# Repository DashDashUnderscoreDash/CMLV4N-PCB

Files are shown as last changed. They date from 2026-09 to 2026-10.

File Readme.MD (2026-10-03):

# **CMLV4N**

CMLV4N is an STM32 12u V4N style PCB with leafspring tadpole mounting featuring forced Cherry ML support

The goal of this PCB is to have a 40% keyboard that uses Cherry ML switches harvested from a Cherry G84-4100.

### PLEASE ENSURE YOU VERIFY THE SPACEBAR IS LARGE ENOUGH!!!! There are multiple models you can use for donor boards and some have too small of spacebar.

Due to the uneven u sizing on Cherry ML the enter key does not fill that entire area. The stabilizer positions for the enter also do not work as they are for a larger sized keycap. This is a compromise that needed to be made to make the layout work and a combination of skill issue. The stabilizer position on the enter does not work as the footprint is the incorrect size. Apologies!

~~Available~~ Sold out at [Dashkeebs](https://dashkeebs.bigcartel.com/product/cmlv4n-pcb) as of 10/1/26

### In this repo you will find:
```
- Layout options
- Images of PCB
- VIAL firmware
- STEP model of PCB
- Edgecuts of PCB
- Complete KiCad project
- Case files (STEP format)
```

VIAL firmware commissioned by [Moinboards.](https://moinboards.de/) Thank you again so much!

### KLC layout
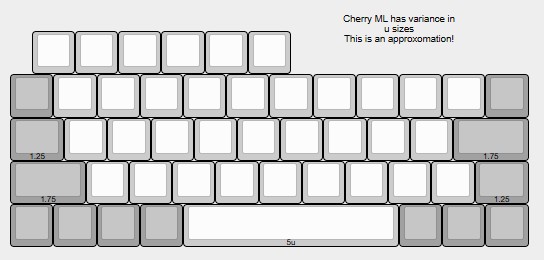
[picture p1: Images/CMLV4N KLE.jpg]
KLC layout


### PCB images
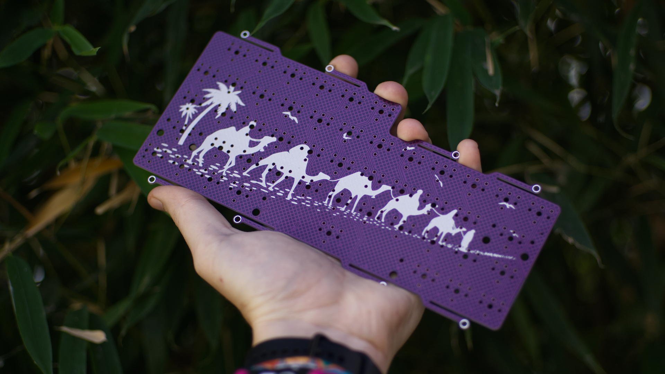
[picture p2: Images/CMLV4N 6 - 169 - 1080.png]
PCB Front

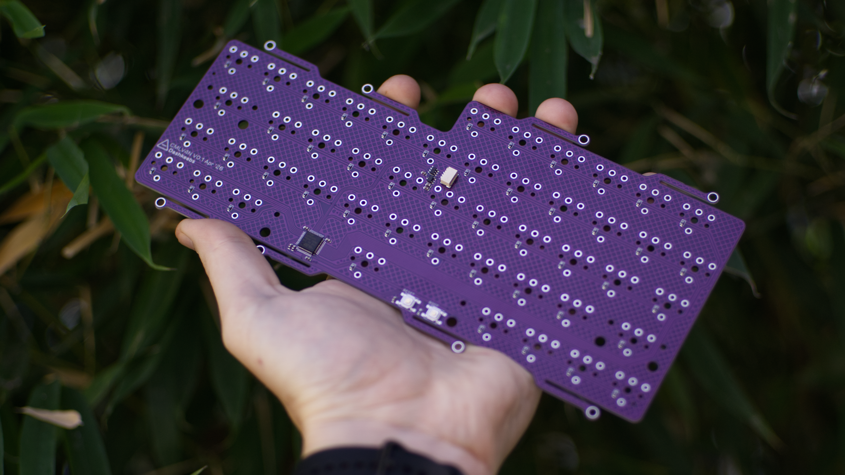
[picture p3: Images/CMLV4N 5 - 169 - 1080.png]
PCB Back


### Case image
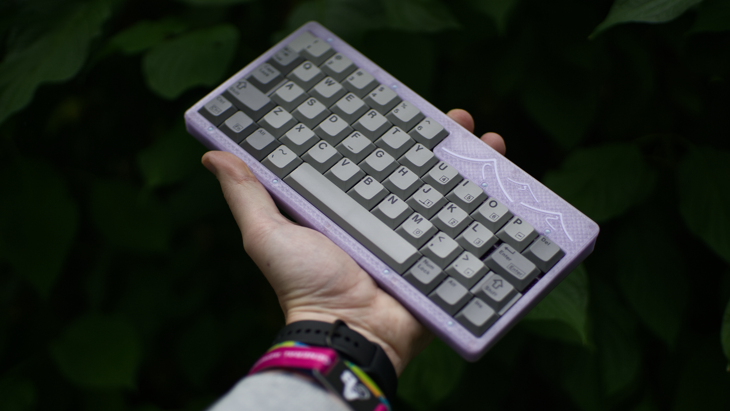
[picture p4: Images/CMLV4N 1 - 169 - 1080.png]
Case


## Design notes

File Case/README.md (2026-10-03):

# **CMLV4N 3d Printed Case**

__Items needed:__
- 1x [C3/C5 universal daughterboard](https://cannonkeys.com/products/unified-daughterboard-and-jst-cable)
- 1x [JST cable](https://www.aliexpress.us/item/3256809955750969.html) - Ideally very short. I used 6cm, 4 pin, "double reverse" cables. Longer cables can be used, but they may negativley impact the flex
- 4x [SKUF feet](https://keeb.io/products/skuf-silicone-rubber-keyboard-feet)
- 8x [Geon tadpoles](https://saberkeebs.com/products/geon-tadpoles) - The softer the better in my opinion
- 8x [M2 heatsets](https://a.co/d/0grCwzam) - *M2/H3/D3 in case link dies in the future*
- 8x [Wheel weights](https://a.co/d/0inzJoTX) - *0.65"/16.4mm X 0.75"/19mm in case link dies in the future*
- 8x M2x5 screws

__Print settings:__
- I used [Bambu translucent PLA](https://us.store.bambulab.com/products/pla-translucent?id=593999615827689541) and a random white PLA I had laying around
- 25% 3D honeycomb infill
- 3 walls for additional strength
- There is front and back art you can use a for multicolor printing. If you want single color, in your slicing software, you can set them the same color
- Supports needed for SKUF feet areas. *Not required, but highly suggested, to use dedicated support material with 0 Z distance. This will give you the flattest surface area possible. When using no supports the bridging will have less surface area and the SKUF may fall off*

__Notes:__
- The screw holes are a bit small, so getting the screws in may take some force
- Only tested in PLA with Bambu filament, default profile, on a P1S with a 0.4 hardened steel nozzle
- I figured this would be a travel board so I went a bit crazy with the screw locations. Don't hate me!

### Case images
Case Front
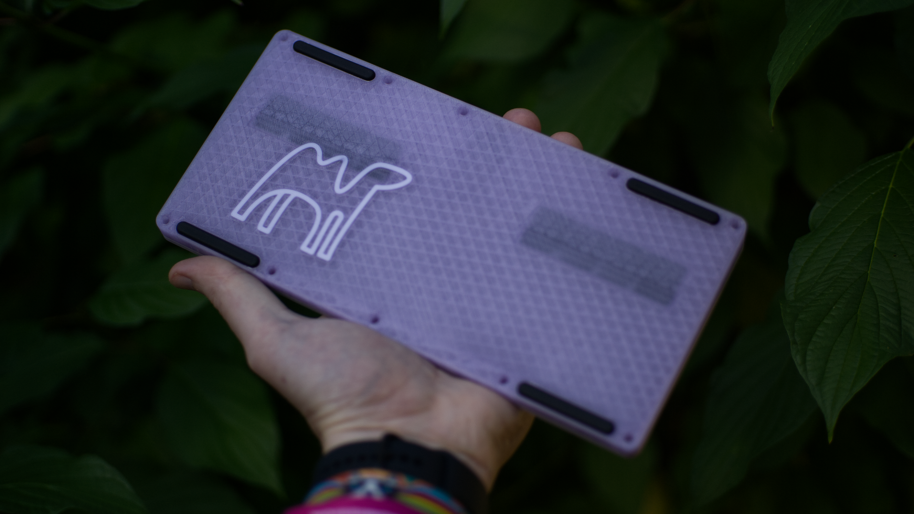
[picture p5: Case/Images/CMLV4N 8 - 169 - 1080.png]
Case back


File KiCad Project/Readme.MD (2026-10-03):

# **CMLV4N KiCad Project**

This is my first fully open source KiCad project!

Made in KiCad 9 as it's working well for me and I'm afraid to upgrade and break things

As of 10/3/26 everything uploads to JLC with no errors less needing to orient some components on JLCPCB
<br>
<br>
<br>
I'm not sure if anything else should be put in this readme, so apologies if any information is missing. Feel free to start an issue or DM me on Discord. Username: dashdashunderscoredash
<br>
<br>
<br>
Due to skill issue, when making production files, some components are not oriented correctly. When placing the components in JLC you will need to change:
__ __
- U4: Transient voltage suppressor
__ __
- U3: Over current protection
__ __

### Incorrect orientation
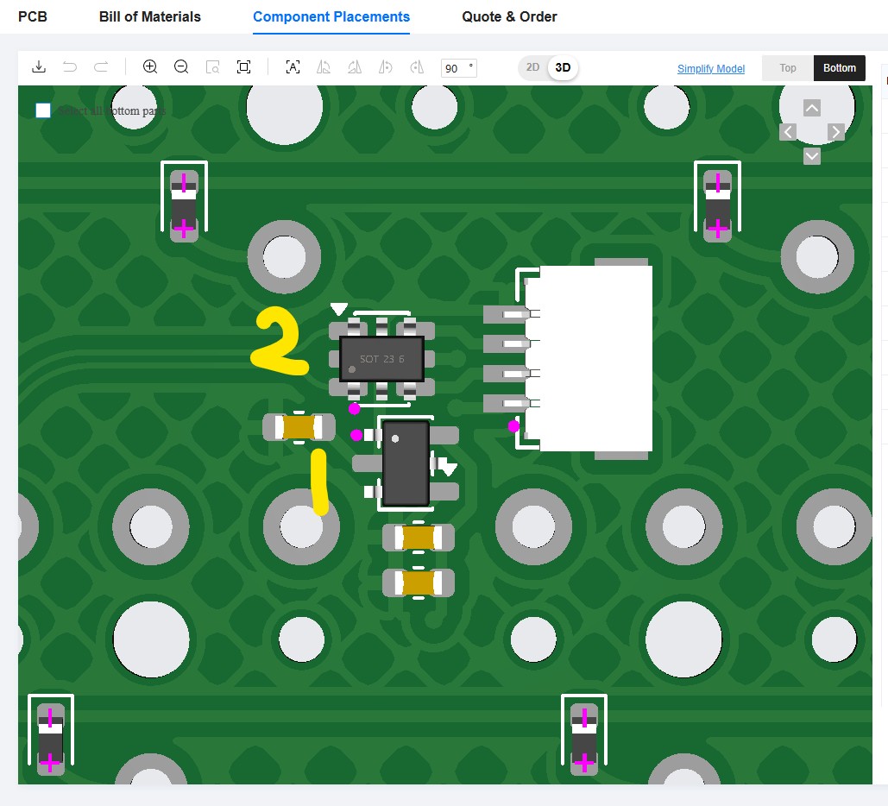
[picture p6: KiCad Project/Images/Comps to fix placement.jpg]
Orientation error 1


### Corrected orientation
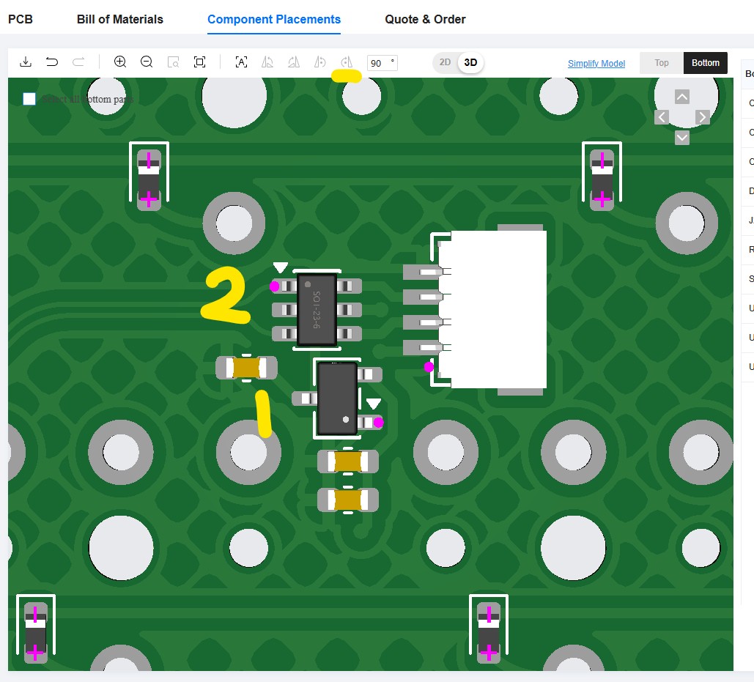
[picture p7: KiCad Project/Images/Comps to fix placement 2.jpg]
Orientation error 2

<br>
<br>
<br>
**Credit:** Leafspring tadpole mount by HaiZeus. Thank you so much for sharing these with me, letting me use on my designs, and helping me learning to design in general. [Please check out his store](https://www.haikey.design/), he's a very talented designer!

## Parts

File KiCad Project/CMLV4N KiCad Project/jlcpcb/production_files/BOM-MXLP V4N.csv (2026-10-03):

Comment | Designator | Footprint | LCSC | Quantity
100nF | C10,C2,C3,C4,C5,C6 | C_0603_1608Metric | C282519 | 6
10k | R1 | R_0603_1608Metric | C2930027 | 1
10uF | C7 | C_0603_1608Metric | C19702 | 1
1uF | C8,C9 | C_0603_1608Metric | C1592 | 2
D_Small | D1,D10,D11,D12,D13,D14,D15,D16,D17,D18,D19,D2,D20,D21,D22,D23,D24,D25,D26,D27,D28,D29,D3,D30,D31,D32,D33,D34,D35,D36,D37,D38,D39,D4,D40,D41,D42,D43,D44,D45,D46,D47,D48,D5,D6,D7,D8,D9 | D_0603_1608Metric | C30584800 | 48
SKQGAFE010 | SW1,SW2 | SW4_SKQGAFE010_ALPS | C202424 | 2
SM04B-SRSS-TB_LF__SN_ | J2 | JST-SR-4 | C51940130 | 1
STM32F072CBT6 | U1 | LQFP-48_7x7mm_P0.5mm | C81720 | 1
USBLC6-2SC6 | U4 | SOT-23-6 | C2687116 | 1
XC6206PxxxMR | U3 | SOT-23-3 | C5446 | 1

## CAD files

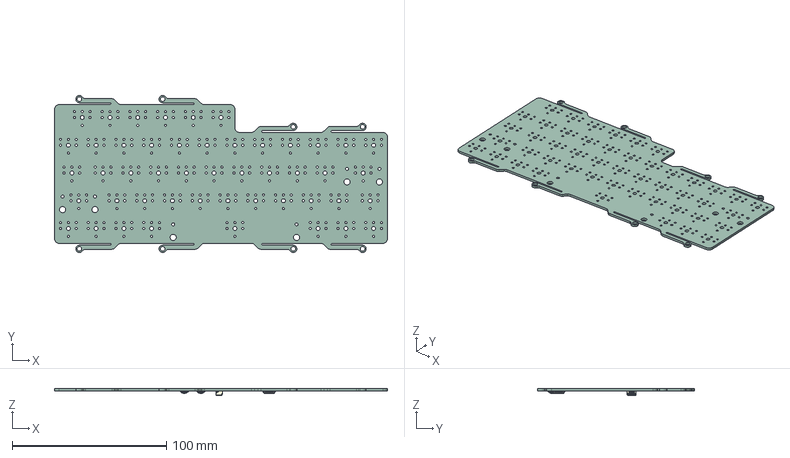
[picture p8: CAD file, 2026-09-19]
3D model/MXLP V4N.step
216.0 x 101.9 x 4.50 mm
SKQGADE010 x 2
SKQGADE010_4 x 2
SKQGADE010_3 x 2
SKQGADE010_7 x 2
SKQGADE010_2 x 2
SKQGADE010_6 x 2
SKQGADE010_5 x 2
LQFP-48_7x7mm_P0.5mm
SM04B-SRSS-TB_LF__SN_
MXLP V4N_PCB

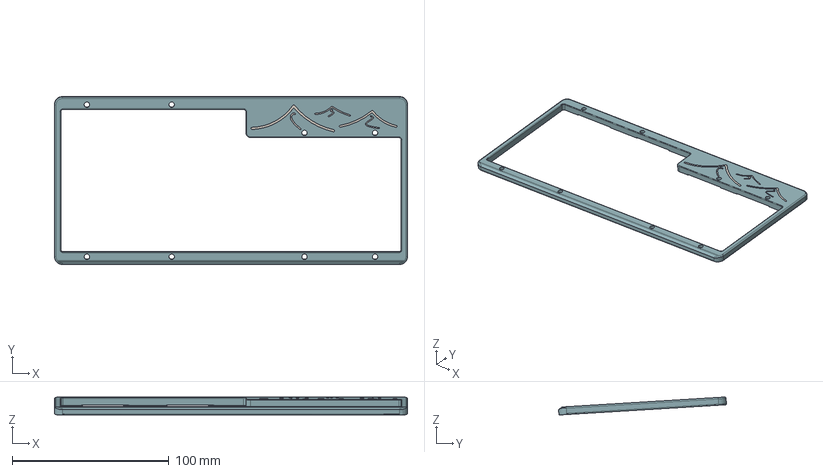
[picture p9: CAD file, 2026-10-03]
Case/CMLV4N Top Case.step
225.0 x 107.0 x 11.4 mm

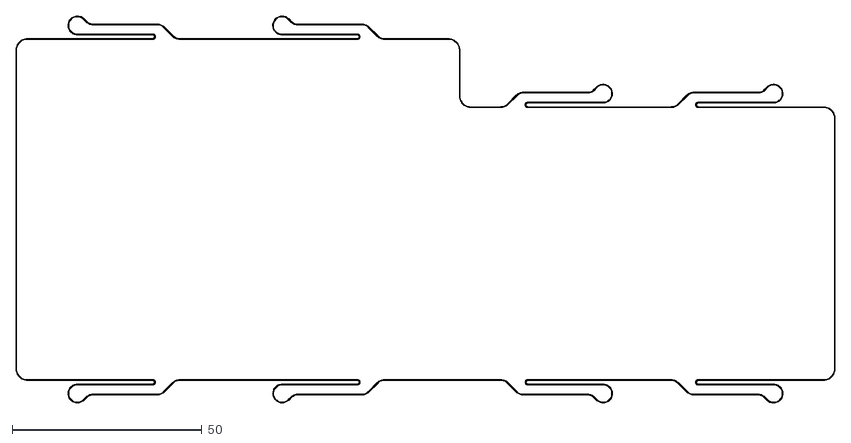
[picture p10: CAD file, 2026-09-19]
KiCad Project/CMLV4N KiCad Project/MXLP V4N-Edge_Cuts.dxf
216.0 x 102.0

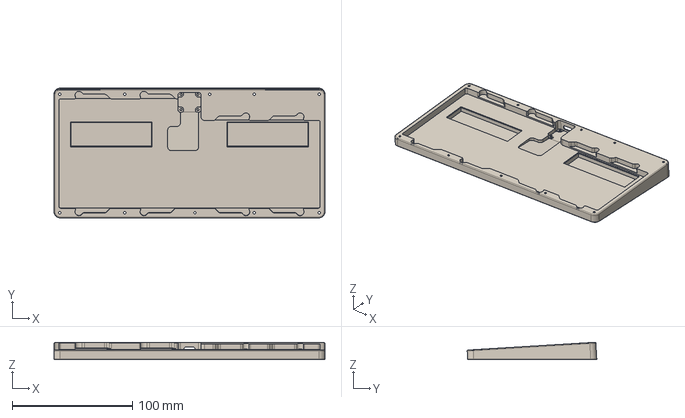
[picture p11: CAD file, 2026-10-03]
Case/CMLV4N Top Bottom.step
225.0 x 107.7 x 14.5 mm

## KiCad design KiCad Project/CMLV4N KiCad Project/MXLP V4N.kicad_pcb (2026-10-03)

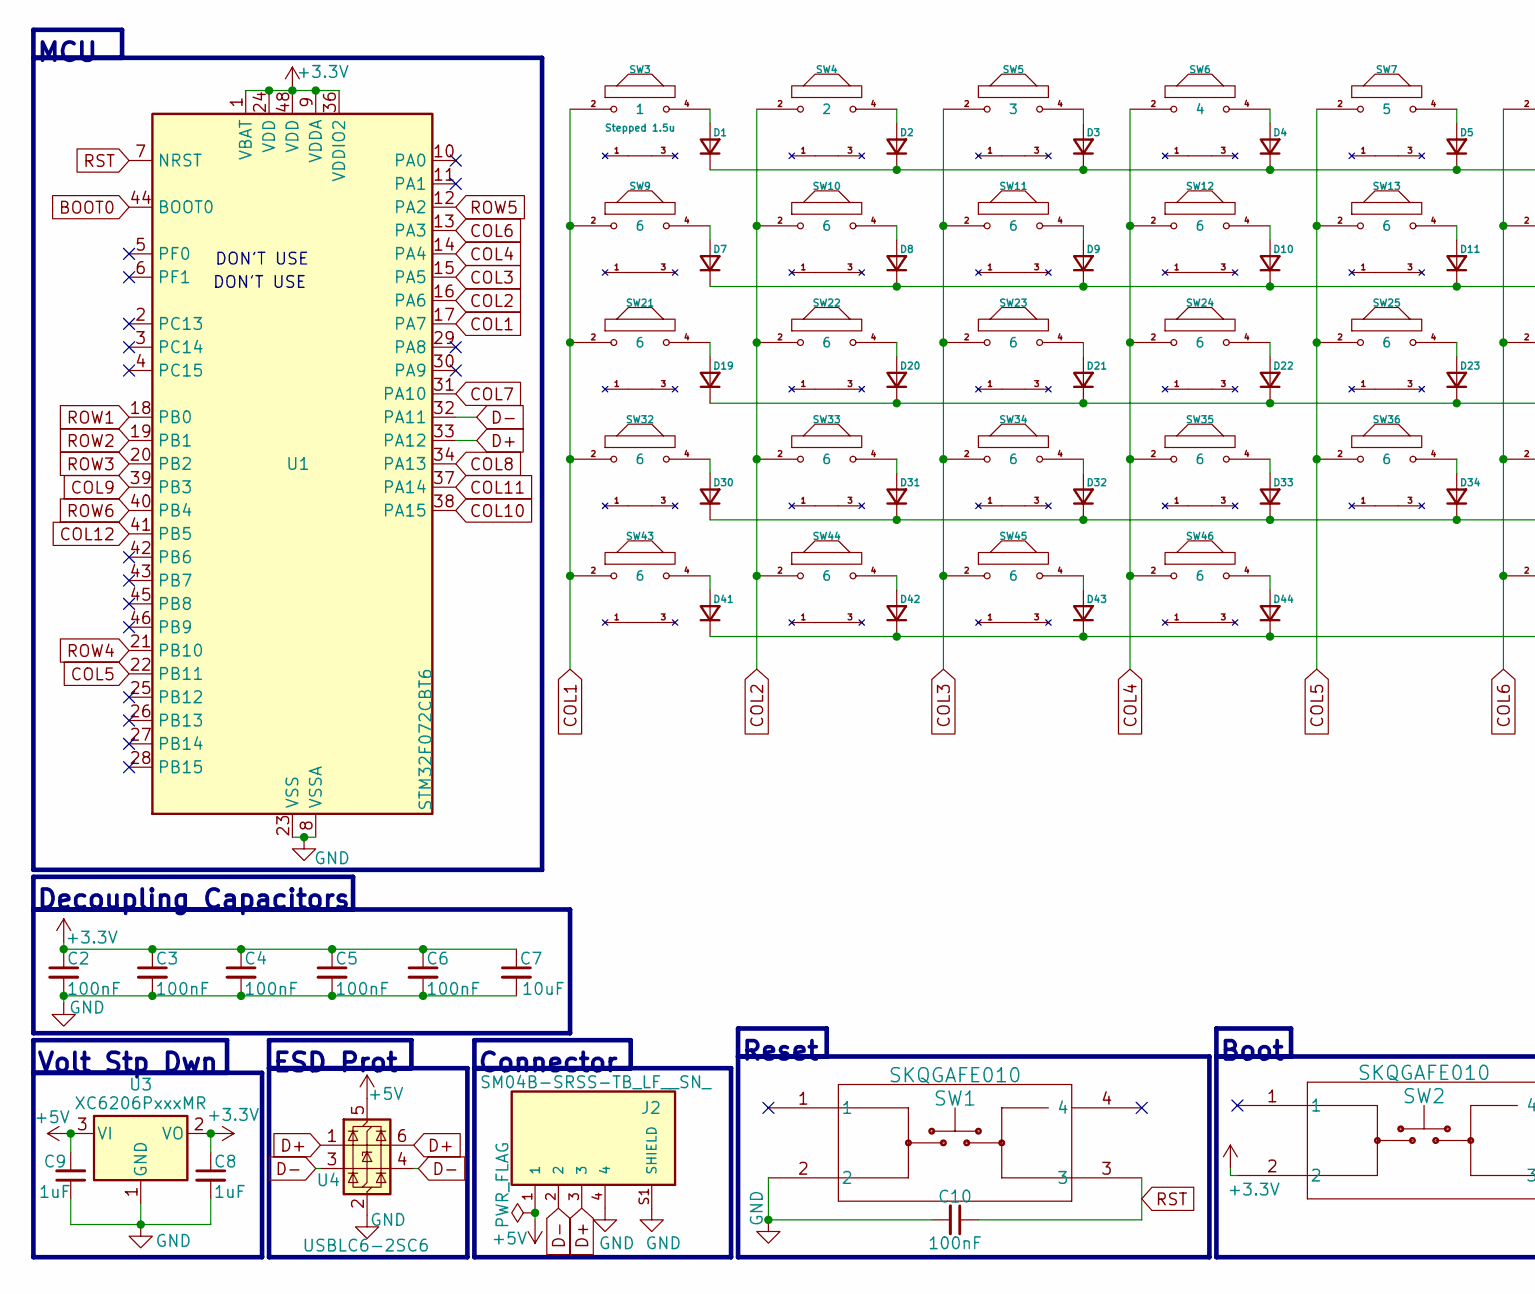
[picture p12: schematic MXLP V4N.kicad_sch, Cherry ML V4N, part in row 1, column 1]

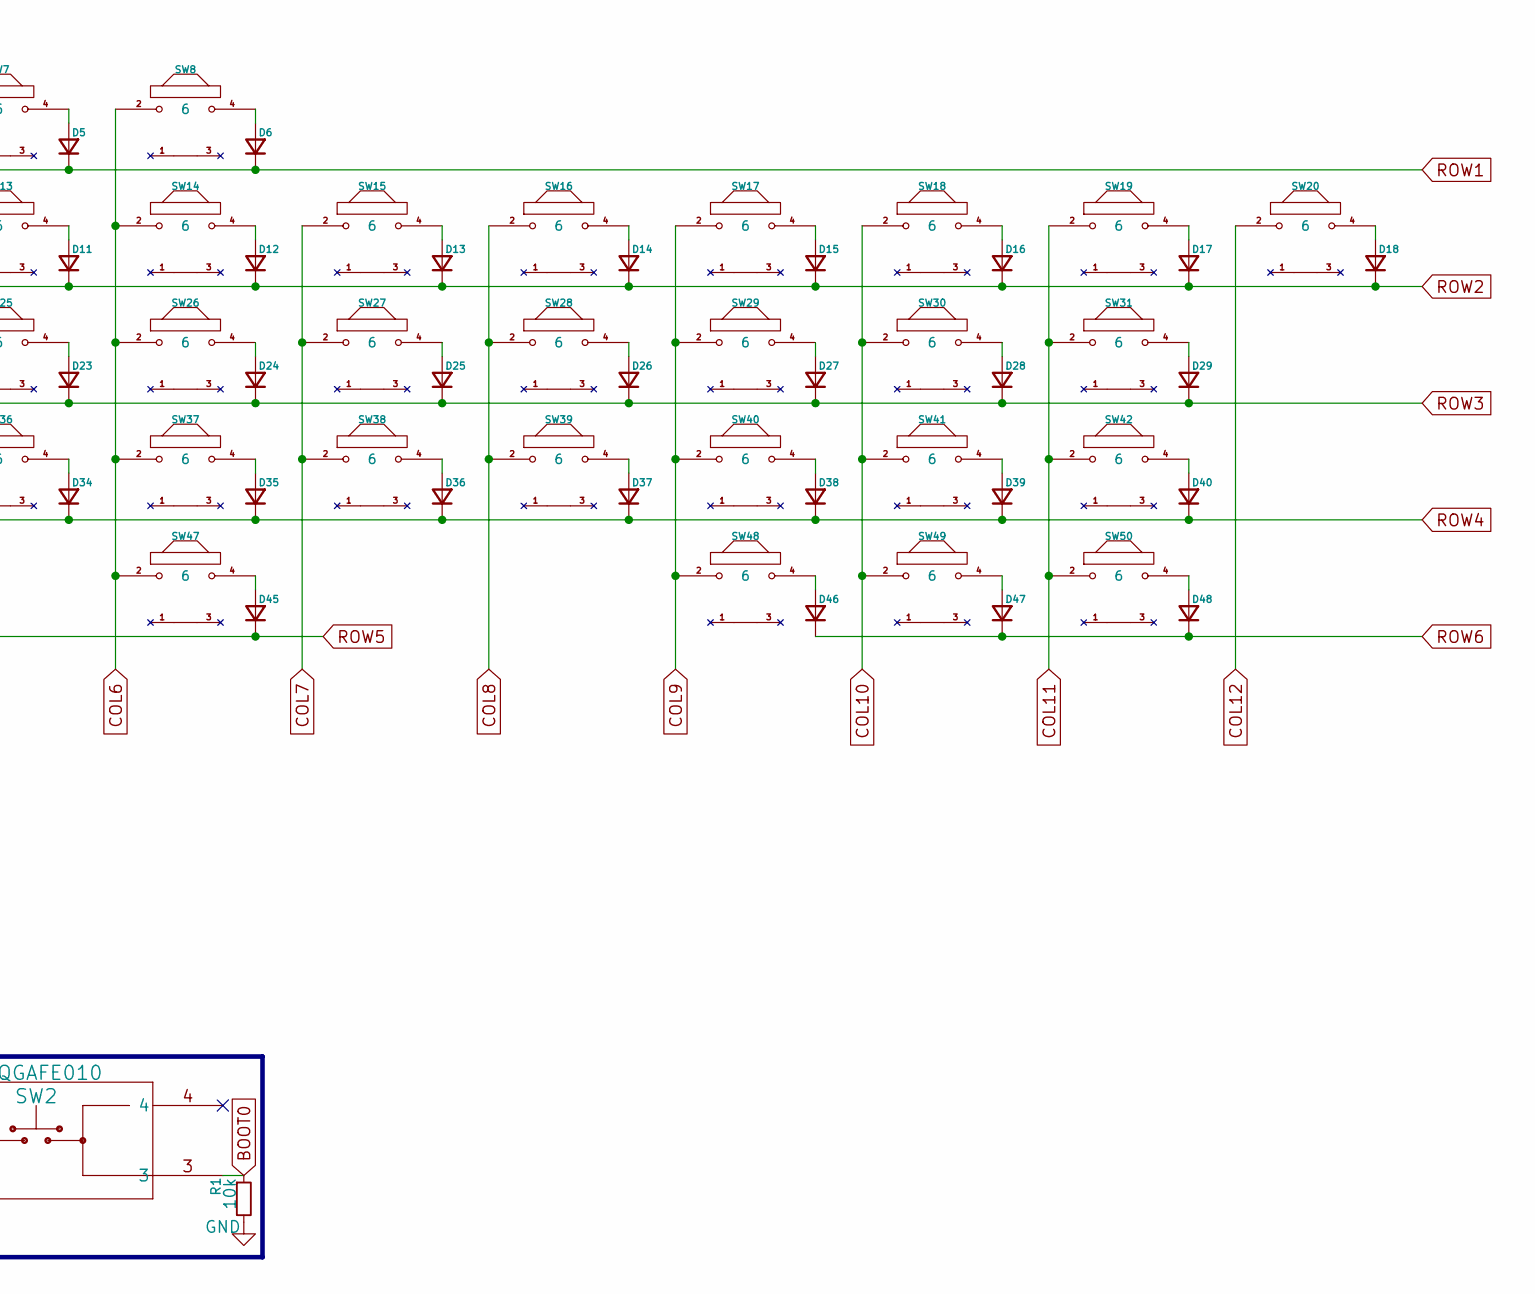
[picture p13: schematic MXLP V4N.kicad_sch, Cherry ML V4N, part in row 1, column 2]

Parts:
C2, C3, C4, C5, C6: 100nF; C_0603_1608Metric; LCSC # C49678
C7: 10uF; C_0603_1608Metric; LCSC # C15850
C8, C9: 1uF; C_0603_1608Metric; LCSC # C28323
C10: 100nF; C_0603_1608Metric
D1, D2, D3, D4, D5, D6, D7, D8, D9, D10, D11, D12, D13, D14, D15, D16, D17, D18, D19, D20, D21, D22, D23, D24, D25, D26, D27, D28, D29, D30, D31, D32, D33, D34, D35, D36, D37, D38, D39, D40, D41, D42, D43, D44, D45, D46, D47, D48: D_Small; D_0603_1608Metric
J2: SM04B-SRSS-TB_LF__SN_; JST-SR-4; LCSC # C51940130
R1: 10k; R_0603_1608Metric; LCSC # C17414
SW1, SW2: SKQGAFE010; SW4_SKQGAFE010_ALPS; LCSC # C202424
SW3: 1; SW_Cherry_ML_1u_Centred_Wired_Correctly
SW4: 2; SW_Cherry_ML_1u_Centred_Wired_Correctly
SW5: 3; SW_Cherry_ML_1u_Centred_Wired_Correctly
SW6: 4; SW_Cherry_ML_1u_Centred_Wired_Correctly
SW7: 5; SW_Cherry_ML_1u_Centred_Wired_Correctly
SW8, SW9, SW10, SW11, SW12, SW13, SW14, SW15, SW16, SW17, SW18, SW19, SW20, SW21, SW22, SW23, SW24, SW25, SW26, SW27, SW28, SW29, SW30, SW31, SW32, SW33, SW34, SW35, SW36, SW37, SW38, SW39, SW40, SW41, SW42, SW43, SW44, SW45, SW46, SW47, SW48, SW49, SW50: 6; SW_Cherry_ML_1u_Centred_Wired_Correctly
U1: STM32F072CBT6; LQFP-48_7x7mm_P0.5mm; LCSC # C81720
U3: XC6206PxxxMR; SOT-23-3; LCSC # C5446
U4: USBLC6-2SC6; SOT-23-6; LCSC # C2687116

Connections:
+3.3V: C2.1, C3.1, C4.1, C5.1, C6.1, C7.1, C8.1, SW2.2, U1.1 (VBAT), U1.9 (VDDA), U1.24 (VDD), U1.36 (VDDIO2), U1.48 (VDD), U3.2 (VO)
+5V: C9.2, J2.1, U3.3 (VI), U4.5 (VBUS)
BOOT0: R1.1, SW2.3, U1.44 (BOOT0)
COL1: SW3.2, SW9.2, SW21.2, SW32.2, SW43.2, U1.17 (PA7)
COL2: SW4.2, SW10.2, SW22.2, SW33.2, SW44.2, U1.16 (PA6)
COL3: SW5.2, SW11.2, SW23.2, SW34.2, SW45.2, U1.15 (PA5)
COL4: SW6.2, SW12.2, SW24.2, SW35.2, SW46.2, U1.14 (PA4)
COL5: SW7.2, SW13.2, SW25.2, SW36.2, U1.22 (PB11)
COL6: SW8.2, SW14.2, SW26.2, SW37.2, SW47.2, U1.13 (PA3)
COL7: SW15.2, SW27.2, SW38.2, U1.31 (PA10)
COL8: SW16.2, SW28.2, SW39.2, U1.34 (PA13)
COL9: SW17.2, SW29.2, SW40.2, SW48.2, U1.39 (PB3)
COL10: SW18.2, SW30.2, SW41.2, SW49.2, U1.38 (PA15)
COL11: SW19.2, SW31.2, SW42.2, SW50.2, U1.37 (PA14)
COL12: SW20.2, U1.41 (PB5)
D+: J2.3, U1.33 (PA12), U4.1 (I/O1), U4.6 (I/O1)
D-: J2.2, U1.32 (PA11), U4.3 (I/O2), U4.4 (I/O2)
GND: C2.2, C3.2, C4.2, C5.2, C6.2, C7.2, C8.2, C9.1, C10.2, J2.4, J2.S1 (SHIELD), J2.S2 (SHIELD), R1.2, SW1.2, U1.8 (VSSA), U1.23 (VSS), U1.35 (VSS), U1.47 (VSS), U3.1 (GND), U4.2 (GND)
unnamed: D1.2 (A), SW3.4
unnamed: D2.2 (A), SW4.4
unnamed: D3.2 (A), SW5.4
unnamed: D4.2 (A), SW6.4
unnamed: D5.2 (A), SW7.4
unnamed: D6.2 (A), SW8.4
unnamed: D7.2 (A), SW9.4
unnamed: D8.2 (A), SW10.4
unnamed: D9.2 (A), SW11.4
unnamed: D10.2 (A), SW12.4
unnamed: D11.2 (A), SW13.4
unnamed: D12.2 (A), SW14.4
unnamed: D13.2 (A), SW15.4
unnamed: D14.2 (A), SW16.4
unnamed: D15.2 (A), SW17.4
unnamed: D16.2 (A), SW18.4
unnamed: D17.2 (A), SW19.4
unnamed: D18.2 (A), SW20.4
unnamed: D19.2 (A), SW21.4
unnamed: D20.2 (A), SW22.4
unnamed: D21.2 (A), SW23.4
unnamed: D22.2 (A), SW24.4
unnamed: D23.2 (A), SW25.4
unnamed: D24.2 (A), SW26.4
unnamed: D25.2 (A), SW27.4
unnamed: D26.2 (A), SW28.4
unnamed: D27.2 (A), SW29.4
unnamed: D28.2 (A), SW30.4
unnamed: D29.2 (A), SW31.4
unnamed: D30.2 (A), SW32.4
unnamed: D31.2 (A), SW33.4
unnamed: D32.2 (A), SW34.4
unnamed: D33.2 (A), SW35.4
unnamed: D34.2 (A), SW36.4
unnamed: D35.2 (A), SW37.4
unnamed: D36.2 (A), SW38.4
unnamed: D37.2 (A), SW39.4
unnamed: D38.2 (A), SW40.4
unnamed: D39.2 (A), SW41.4
unnamed: D40.2 (A), SW42.4
unnamed: D41.2 (A), SW43.4
unnamed: D42.2 (A), SW44.4
unnamed: D43.2 (A), SW45.4
unnamed: D44.2 (A), SW46.4
unnamed: D45.2 (A), SW47.4
unnamed: D46.2 (A), SW48.4
unnamed: D47.2 (A), SW49.4
unnamed: D48.2 (A), SW50.4
ROW1: D1.1 (K), D2.1 (K), D3.1 (K), D4.1 (K), D5.1 (K), D6.1 (K), U1.18 (PB0)
ROW2: D7.1 (K), D8.1 (K), D9.1 (K), D10.1 (K), D11.1 (K), D12.1 (K), D13.1 (K), D14.1 (K), D15.1 (K), D16.1 (K), D17.1 (K), D18.1 (K), U1.19 (PB1)
ROW3: D19.1 (K), D20.1 (K), D21.1 (K), D22.1 (K), D23.1 (K), D24.1 (K), D25.1 (K), D26.1 (K), D27.1 (K), D28.1 (K), D29.1 (K), U1.20 (PB2)
ROW4: D30.1 (K), D31.1 (K), D32.1 (K), D33.1 (K), D34.1 (K), D35.1 (K), D36.1 (K), D37.1 (K), D38.1 (K), D39.1 (K), D40.1 (K), U1.21 (PB10)
ROW5: D41.1 (K), D42.1 (K), D43.1 (K), D44.1 (K), D45.1 (K), U1.12 (PA2)
ROW6: D46.1 (K), D47.1 (K), D48.1 (K), U1.40 (PB4)
RST: C10.1, SW1.3, U1.7 (NRST)

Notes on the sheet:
Decoupling Capacitors
DON'T USE
ESD Prot
Boot
Connector
Volt Stp Dwn
Reset
MCU

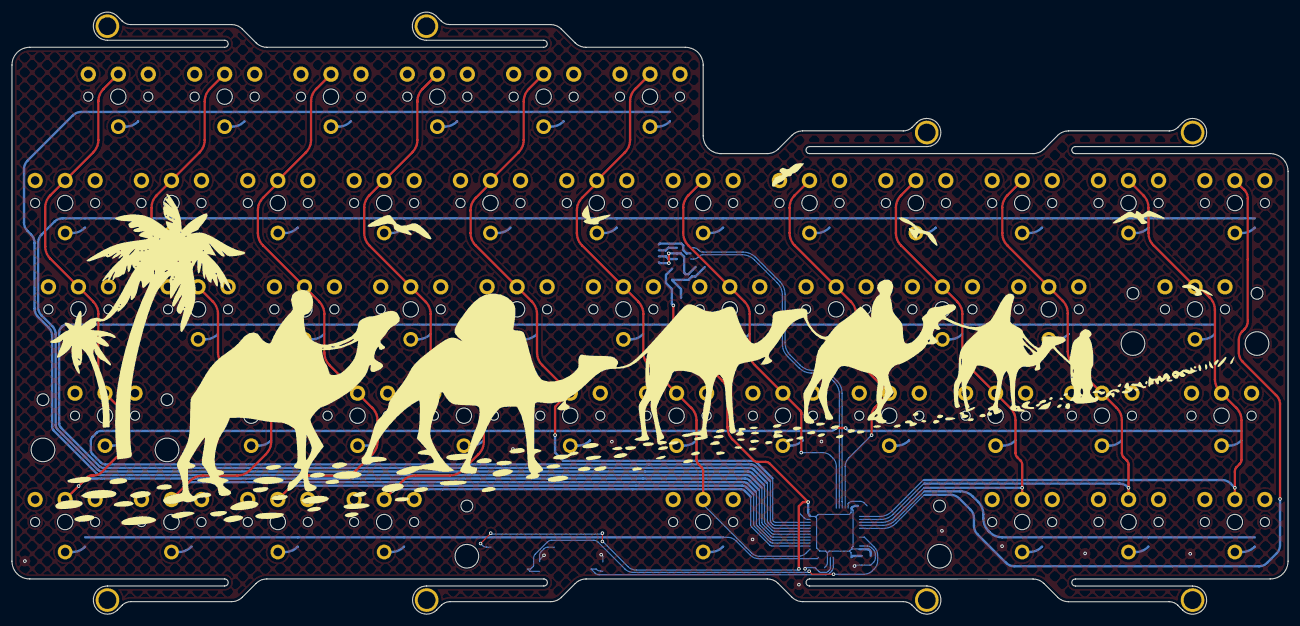
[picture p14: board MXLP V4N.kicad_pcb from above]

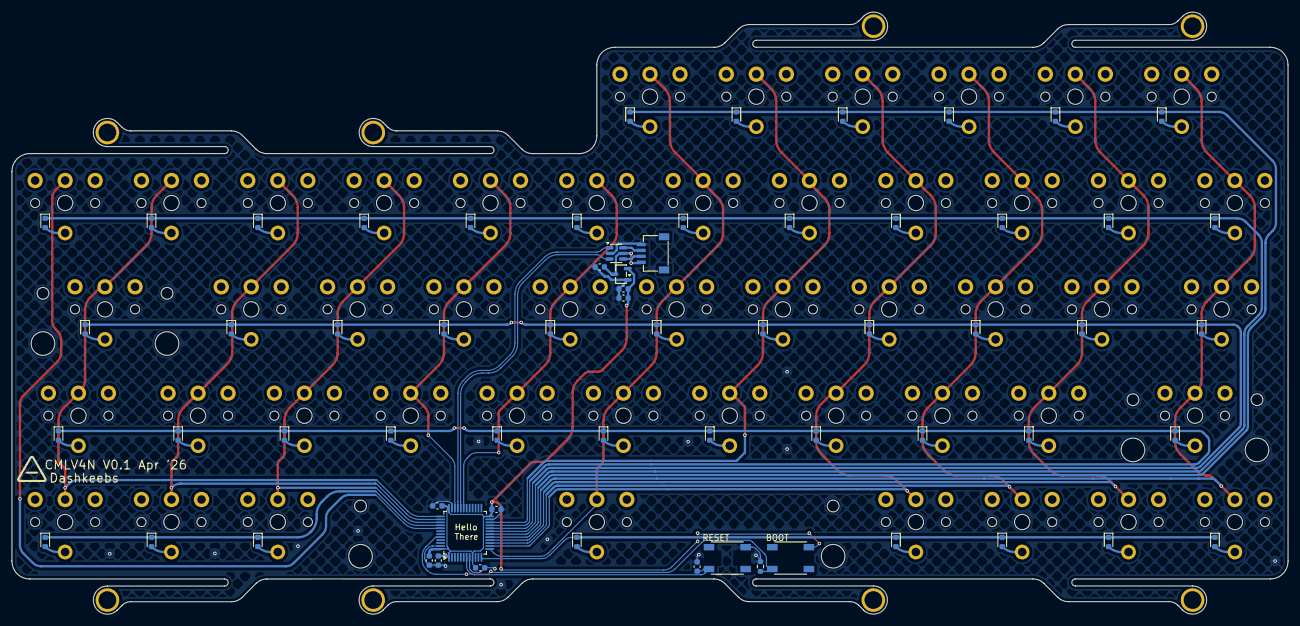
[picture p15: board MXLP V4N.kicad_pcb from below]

Board: 2 copper layers, 216.0 x 101.9 mm, 120 parts (64 on the bottom side), 73 nets.

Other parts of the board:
Ref**: Tadpole_Flex; HaiZeus_Tadpole_Flex
Ref**#2, Ref**#4, Ref**#7: Tadpole_Flex; HaiZeus_Tadpole_Flex
Ref**#3, Ref**#5, Ref**#6, Ref**#8: Tadpole_Flex; HaiZeus_Tadpole_Flex_Flipped

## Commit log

2026-09-19 Make repo
    [MXLP V4N-Edge_Cuts.dxf, MXLP V4N.step]
2026-10-02 Change PCB availability to 'Sold out' and update contents
    Updated availability status of PCB on Dashkeebs and added VIAL firmware to the list of contents.
2026-10-03 Update spacebar verification note in Readme
    Clarified note about verifying spacebar size for donor boards.
2026-10-03 Add KiCad project
    [BOM-MXLP V4N.csv, MXLP V4N-Edge_Cuts.dxf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]
2026-10-03 Update Readme to include case files
    Added case files in STEP format to the documentation.
2026-10-03 Add case image to the Readme
2026-10-03 Adding case files
    [CMLV4N Top Bottom.step, CMLV4N Top Case.step]
